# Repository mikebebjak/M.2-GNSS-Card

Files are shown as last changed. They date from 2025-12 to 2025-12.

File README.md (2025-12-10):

There are plenty of USB GNSS modules but very few M.2 modules for PCs. This project sought to rectify this issue by using a u-Blox M8C chip on a M.2 card. This way you can add GNSS to any PC when customers do not want to use external USB dongles. 
This card uses an HF4 antenna header for an external antenna (either direct or through a converter cable).
You can also download u-Blox software to test it out in Windows, as the attached screenshot shows.
Hopefully this helps someone!





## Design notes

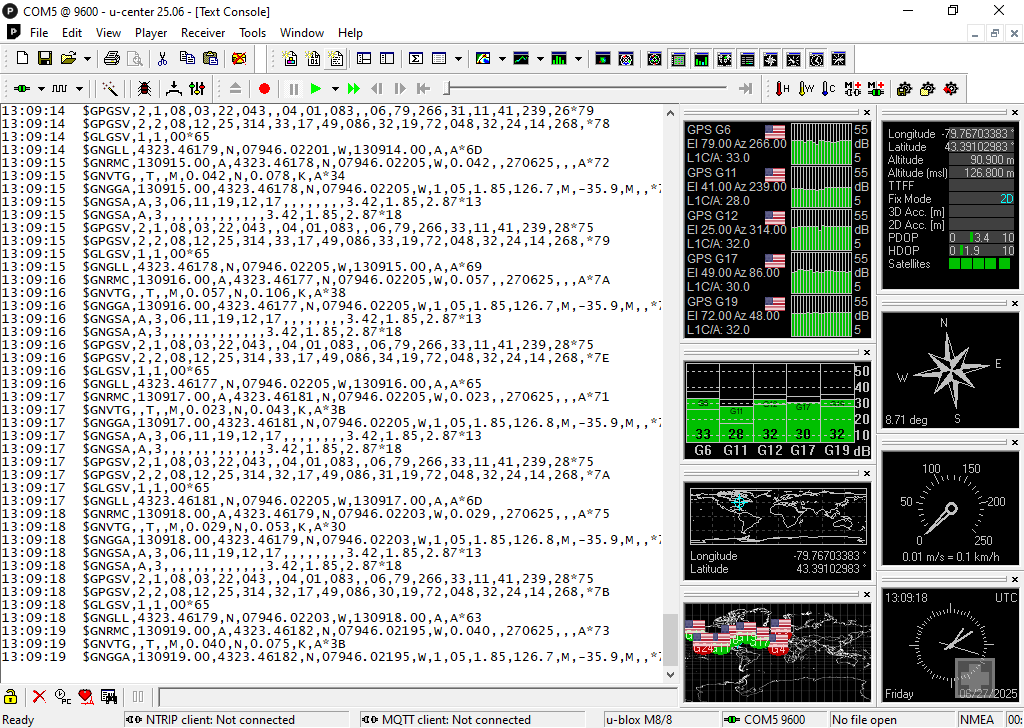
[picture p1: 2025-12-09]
gps.png

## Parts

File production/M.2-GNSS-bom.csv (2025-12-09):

Comment | Designator | Footprint | JLCPCB Part #
SP1001-02JTG | D1,D2 | SOT-323_SC-70 | C151300
FT230XQ | U3 | QFN-16-1EP_4x4mm_P0.65mm_EP2.1x2.1mm | C128629
100nF | C5,C3 | C_0402_1005Metric | C1525
Battery_Cell | BT1 | BAT_3030TR
520R | R14 | R_0402_1005Metric | C365029
NET | LED1 | LED_0402_1005Metric
10R | R3 | R_0402_1005Metric
4.7K | R2,R1 | R_0402_1005Metric
22uF | C6 | C_0603_1608Metric
0.1uF | C1 | C_0402_1005Metric | C1525
10nH | L1 | C_0402_1005Metric_Pad0.74x0.62mm_HandSolder
CONMHF4-SMD-G-T | ACT_ANT | LINX_CONMHF4-SMD-G-T | C18221168
MAX-M8C-0-10 | U1 | MAX-8 MAX-M8_UBL

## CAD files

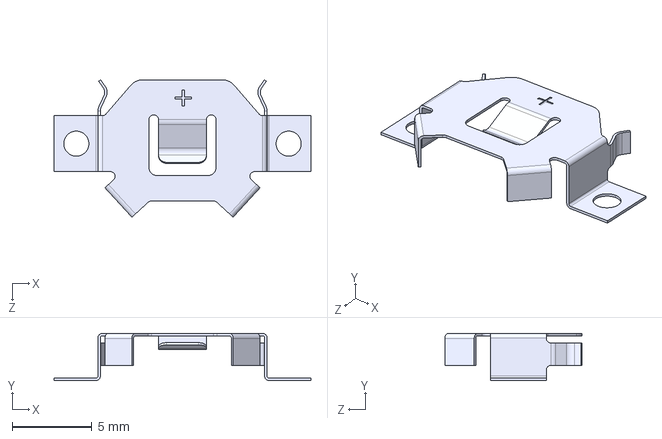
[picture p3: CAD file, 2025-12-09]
EDA/3030TR/3030TR.step
16.1 x 2.95 x 8.61 mm

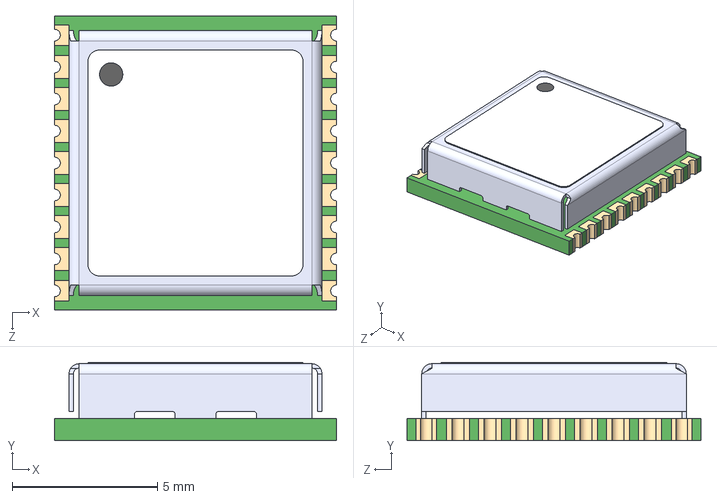
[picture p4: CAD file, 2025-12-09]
EDA/MAX_M8C_0_10/MAX-M8C-0-10--3DModel-STEP-56544.STEP
9.70 x 2.70 x 10.1 mm

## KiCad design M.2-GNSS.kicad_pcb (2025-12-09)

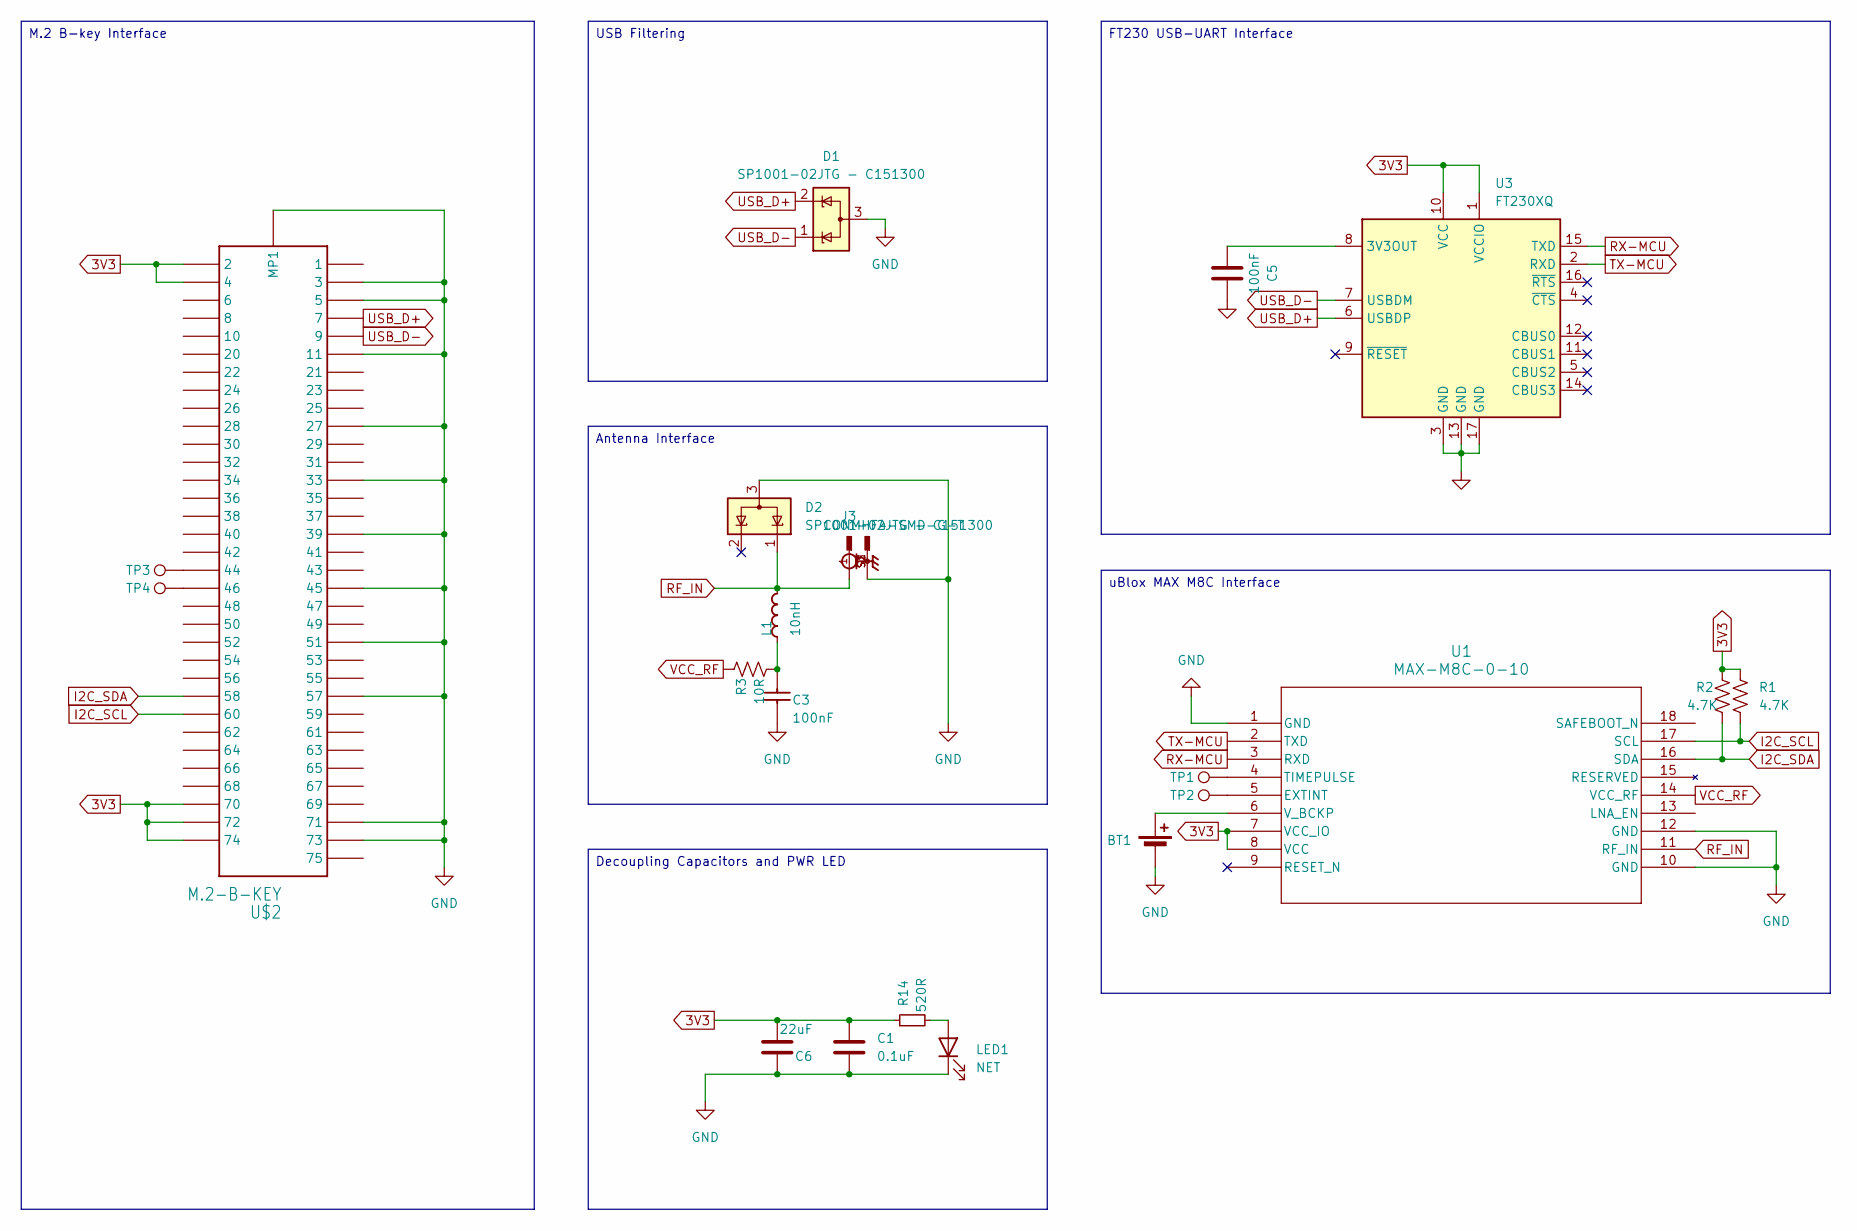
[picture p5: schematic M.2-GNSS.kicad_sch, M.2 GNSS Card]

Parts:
BT1: Battery_Cell; BAT_3030TR
C1: 0.1uF; C_0402_1005Metric
C3: 100nF; C_0402_1005Metric; PART NUMBER C0402-0.8p
C5: 100nF; C_0402_1005Metric
C6: 22uF; C_0603_1608Metric
D1, D2: SP1001-02JTG - C151300; SOT-323_SC-70
J3: CONMHF4-SMD-G-T; LINX_CONMHF4-SMD-G-T
L1: 10nH; C_0402_1005Metric_Pad0.74x0.62mm_HandSolder; PART NUMBER L0402-4n7
LED1: NET; LED_0402_1005Metric
R1, R2: 4.7K; R_0402_1005Metric
R3: 10R; R_0402_1005Metric
R14: 520R; R_0402_1005Metric
TP1: TIMEPULSE; TestPoint_Pad_D1.5mm
TP2: EXTINT; TestPoint_Pad_D1.5mm
TP3: GPIO2; TestPoint_Pad_D1.5mm
TP4: GPIO3; TestPoint_Pad_D1.5mm
U1: MAX-M8C-0-10; MAX-8&slash_MAX-M8_UBL
U3: FT230XQ; QFN-16-1EP_4x4mm_P0.65mm_EP2.1x2.1mm
U$2: M.2-B-KEY

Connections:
3V3: C1.2, C6.1, R1.1, R2.1, R14.1, U1.7 (VCC_IO), U1.8 (VCC), U3.1 (VCCIO), U3.10 (VCC), U$2.P$2 (2), U$2.P$4 (4), U$2.P$70 (70), U$2.P$72 (72), U$2.P$74 (74)
GND: BT1.2 (-), C1.1, C3.1, C5.1, C6.2, D1.3 (A), D2.3 (A), J3.S1, J3.S2, J3.S3, LED1.1 (K), U1.1 (GND), U1.10 (GND), U1.12 (GND), U3.3 (GND), U3.13 (GND), U3.17 (GND), U$2.MOUNTING-HOLE (MP1), U$2.P$3 (3), U$2.P$5 (5), U$2.P$11 (11), U$2.P$27 (27), U$2.P$33 (33), U$2.P$39 (39), U$2.P$45 (45), U$2.P$51 (51), U$2.P$57 (57), U$2.P$71 (71), U$2.P$73 (73); also elsewhere on the board
I2C_SCL: R1.2, U1.17 (SCL), U$2.P$60 (60)
I2C_SDA: R2.2, U1.16 (SDA), U$2.P$58 (58)
unnamed: BT1.1 (+), U1.6 (V_BCKP)
unnamed: C3.2, L1.1, R3.2
unnamed: LED1.2 (A), R14.2
unnamed: TP2.1, U1.5 (EXTINT)
unnamed: TP1.1, U1.4 (TIMEPULSE)
unnamed: C5.2, U3.8 (3V3OUT)
unnamed: TP3.1, U$2.P$44 (44)
unnamed: TP4.1, U$2.P$46 (46)
RF_IN: D2.1 (K), J3.1, L1.2, U1.11 (RF_IN); also elsewhere on the board
RX-MCU: U1.3 (RXD), U3.15 (TXD)
TX-MCU: U1.2 (TXD), U3.2 (RXD)
USB_D+: D1.2 (K), U3.6 (USBDP), U$2.P$7 (7)
USB_D-: D1.1 (K), U3.7 (USBDM), U$2.P$9 (9)
VCC_RF: R3.1, U1.14 (VCC_RF)

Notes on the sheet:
FT230 USB-UART Interface
Antenna Interface
M.2 B-key Interface
Decoupling Capacitors and PWR LED
USB Filtering
uBlox MAX M8C Interface

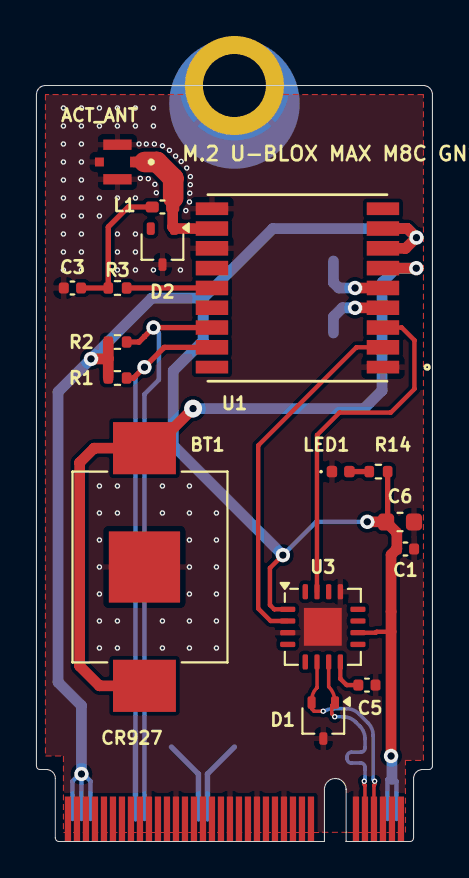
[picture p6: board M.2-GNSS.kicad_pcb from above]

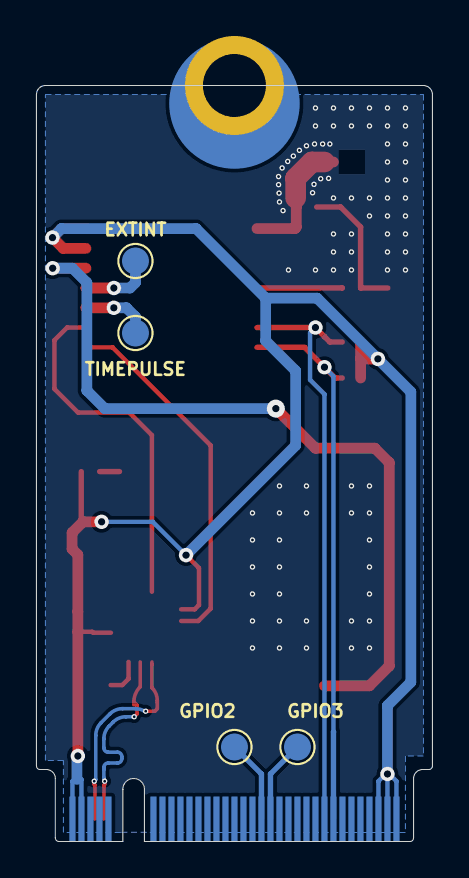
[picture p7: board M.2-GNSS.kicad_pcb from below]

Board: 2 copper layers, 22.0 x 42.0 mm, 21 parts (4 on the bottom side), 18 nets.

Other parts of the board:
ACT_ANT: CONMHF4-SMD-G-T; LINX_CONMHF4-SMD-G-T

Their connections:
GND: ACT_ANT.S1, ACT_ANT.S2, ACT_ANT.S3; also elsewhere on the board
RF_IN: ACT_ANT.1; also elsewhere on the board
